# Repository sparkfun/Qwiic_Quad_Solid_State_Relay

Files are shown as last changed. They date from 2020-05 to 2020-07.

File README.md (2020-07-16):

SparkFun Qwiic Quad Solid State Relay Kit
========================================

SparkFun Qwiic Dual Solid State Relay

[*SparkFun Qwiic Dual Solid State Relay Kit (KIT-16833)*](https://www.sparkfun.com/products/16833)

The SparkFun Quad Solid State Relay Kit comes with four solid state relays you can assemble on to a single board allowing you to control all of them from a microcontroller via I<sup>2</sup>C with the Qwiic Ecosystem. The relays are rated for 40A @28-380VAC allowing you to harness some serious high voltage power from simple I<sup>2</sup>C commands from your favorite microcontroller.

The Qwiic Quad Solid State Relay comes requires some basic assembly to attach the relays and connect your AC load. It uses the simple [Qwiic interface](https://www.sparkfun.com/qwiic). No soldering, no voltage translation, no figuring out which pin is SDA or SCL, just plug and go!

**Note:** Controlling high voltage (110/220VAC) requires certain precautions. A beginner can do it but if you're wary of working with high voltage, you may want to consider the pre-made [IoT Power Relay](https://www.sparkfun.com/products/14236). It's not controlled via I<sup>2</sup>C but the IoT Power Relay contains shielding to prevent accidental shock.

Repository Contents
-------------------

* **/Documentation** - Data sheets, additional product information
* **/Firmware** - Latest firmware
* **/Hardware** - Eagle design files (.brd, .sch)
* **/Production** - Production panel files (.brd)

Documentation
--------------
* **[SparkFun Qwiic Relay Arduino Library](https://github.com/sparkfun/SparkFun_Qwiic_Relay_Arduino_Library)** - Arduino library for SparkFun Qwiic Relay boards.
* **[Hookup Guide](https://learn.sparkfun.com/tutorials/sparkfun-qwiic-quad-solid-state-relay-kit-hookup-guide)** - Basic hookup guide for the Qwiic Dual Solid State Relay.

Product Versions
----------------
* [KIT-16833](https://www.sparkfun.com/products/16810)- Initial release of the Qwiic Quad Solid State Relay Kit.

License Information
-------------------

This product is _**open source**_! 

Please review the LICENSE.md file for license information. 

If you have any questions or concerns on licensing, please contact technical support on our [SparkFun forums](https://forum.sparkfun.com/viewforum.php?f=152).

Distributed as-is; no warranty is given.

- Your friends at SparkFun.

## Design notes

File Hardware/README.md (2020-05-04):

SparkFun <PRODUCT NAME> Design Files
=====================================

The .sch and .brd files hare are Eagle CAD schematic and PCB design files from SparkFun Electronics.
A freeware version of Eagle can be found [here](http://www.cadsoftusa.com/download-eagle/freeware/).

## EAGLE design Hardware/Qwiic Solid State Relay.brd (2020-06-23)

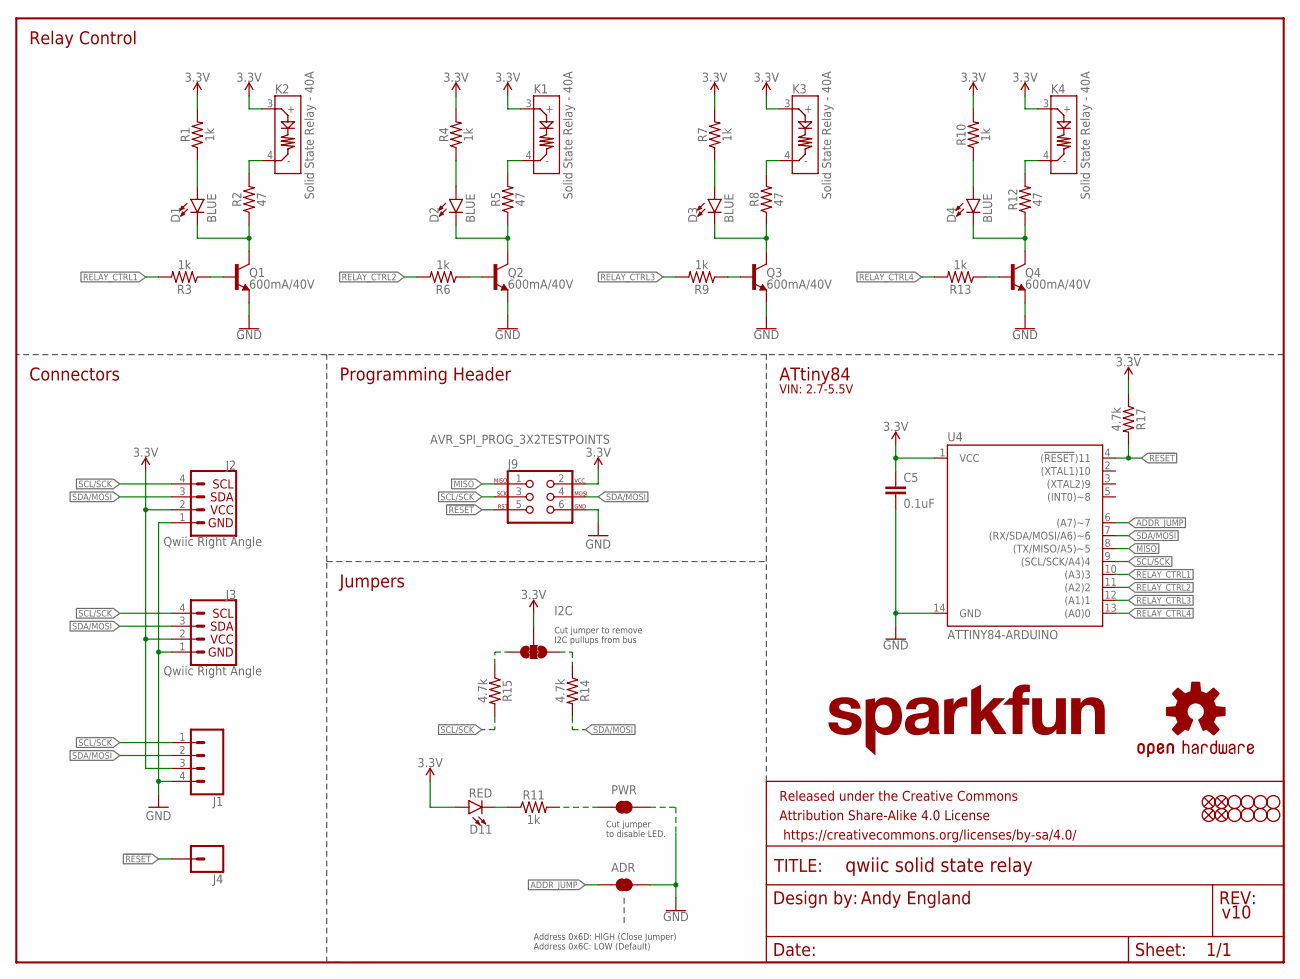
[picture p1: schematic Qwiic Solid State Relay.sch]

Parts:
ADR: JUMPER-SMT_2_NC_TRACE_SILK; SMT-JUMPER_2_NC_TRACE_SILK
C5: 0.1uF; 0603
D1, D2, D3, D4: BLUE; LED-0603
D11: RED; LED-0603
FD1, FD2, FD3, FD4: FIDUCIAL1X2; FIDUCIAL-1X2
FRAME1: FRAME-LETTER; CREATIVE_COMMONS
I2C: JUMPER-SMT_3_2-NC_TRACE_SILK; SMT-JUMPER_3_2-NC_TRACE_SILK
J1: CONN_041X04_NO_SILK; 1X04_NO_SILK
J2, J3: Qwiic Right Angle; JST04_1MM_RA
J4: CONN_01PTH_NO_SILK_YES_STOP; 1X01_NO_SILK
J9: AVR_SPI_PROG_3X2TESTPOINTS; 2X3_TEST_POINTS
JP1, JP2, JP3, JP4, JP5, JP6, JP7, JP8: STAND-OFF
K1, K2, K3, K4: Solid State Relay - 40A; SSR-40DA-H
LOGO1: SFE_LOGO_NAME1_INCH; SFE_LOGO_NAME_1
LOGO2: OSHW-LOGOS; OSHW-LOGO-S
PWR: JUMPER-SMT_2_NC_TRACE_SILK; SMT-JUMPER_2_NC_TRACE_SILK
Q1, Q2, Q3, Q4: 600mA/40V; SOT23-3
R1, R3, R4, R6, R7, R9, R10, R11, R13: 1k; 0603
R2, R5, R8, R12: 47; 0603
R14, R15, R17: 4.7k; 0603
U4: ATTINY84-ARDUINO; SO14

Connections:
3.3V: C5.1, D11.A, I2C.2, J1.3, J2.2, J3.2, J9.2, K1.3 (+), K2.3 (+), K3.3 (+), K4.3 (+), R1.2, R4.2, R7.2, R10.2, R17.1, U4.1 (VCC)
!RESET: J4.1, J9.5, R17.2, U4.4 ((!RESET!)11)
ADDR_JUMP: ADR.1, U4.6 ((A7)~7)
GND: ADR.2, C5.2, J1.4, J2.1, J3.1, J9.6, PWR.1, Q1.2 (E), Q2.2 (E), Q3.2 (E), Q4.2 (E), U4.14 (GND)
MISO: J9.1, U4.8 ((TX/MISO/A5)~5)
unnamed: D2.C, Q2.3 (C), R5.1
unnamed: D1.C, Q1.3 (C), R2.1
unnamed: K1.4 (-), R5.2
unnamed: D2.A, R4.1
unnamed: D3.C, Q3.3 (C), R8.1
unnamed: K3.4 (-), R8.2
unnamed: D1.A, R1.1
unnamed: D3.A, R7.1
unnamed: D4.C, Q4.3 (C), R12.1
unnamed: K2.4 (-), R2.2
unnamed: K4.4 (-), R12.2
unnamed: D4.A, R10.1
unnamed: D11.C, R11.1
unnamed: PWR.2, R11.2
unnamed: I2C.3, R15.1
unnamed: I2C.1, R14.1
OPTO_1: Q1.1 (B), R3.1
OPTO_2: Q2.1 (B), R6.1
OPTO_3: Q3.1 (B), R9.1
OPTO_4: Q4.1 (B), R13.1
RELAY_CTRL1: R3.2, U4.10 ((A3)3)
RELAY_CTRL2: R6.2, U4.11 ((A2)2)
RELAY_CTRL3: R9.2, U4.12 ((A1)1)
RELAY_CTRL4: R13.2, U4.13 ((A0)0)
SCL/SCK: J1.1, J2.4, J3.4, J9.3, R15.2, U4.9 ((SCL/SCK/A4)4)
SDA/MOSI: J1.2, J2.3, J3.3, J9.4, R14.2, U4.7 ((RX/SDA/MOSI/A6)~6)

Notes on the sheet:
Andy England
v10
Connectors
ATtiny84
Programming Header
Address 0x6D: HIGH (Close Jumper) Address 0x6C: LOW (Default)
Cut jumper to disable LED.
Jumpers
Relay Control
Cut jumper to remove I2C pullups from bus
VIN: 2.7-5.5V

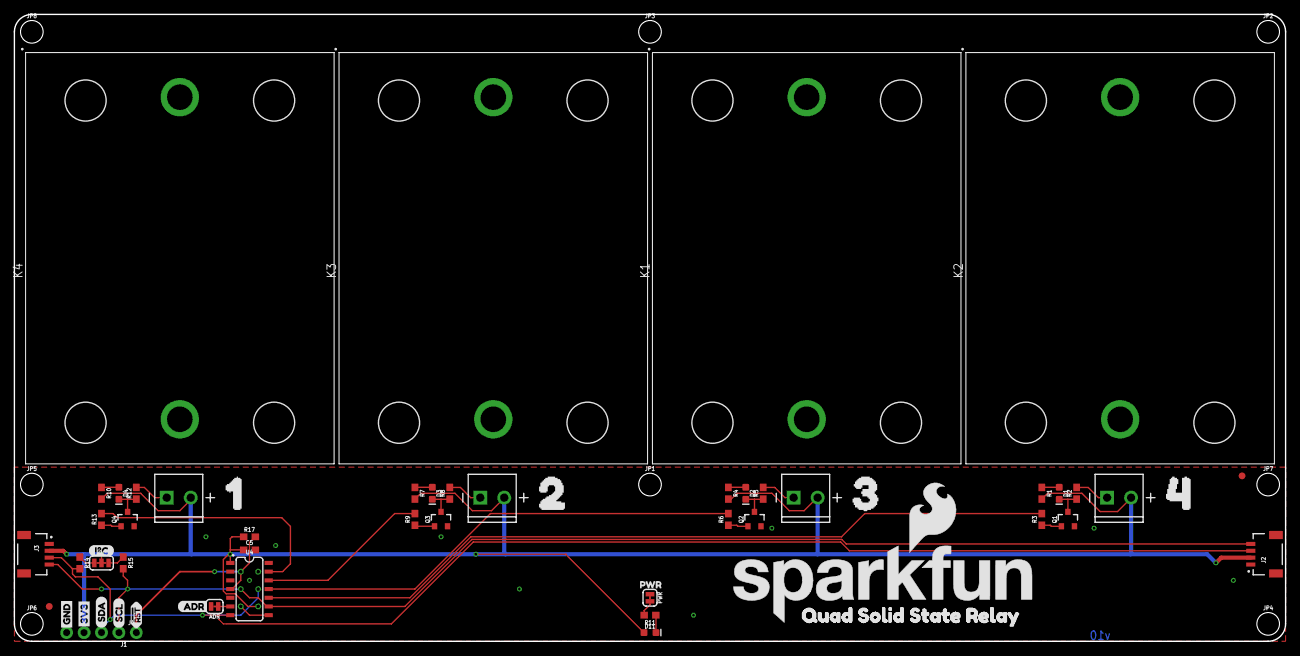
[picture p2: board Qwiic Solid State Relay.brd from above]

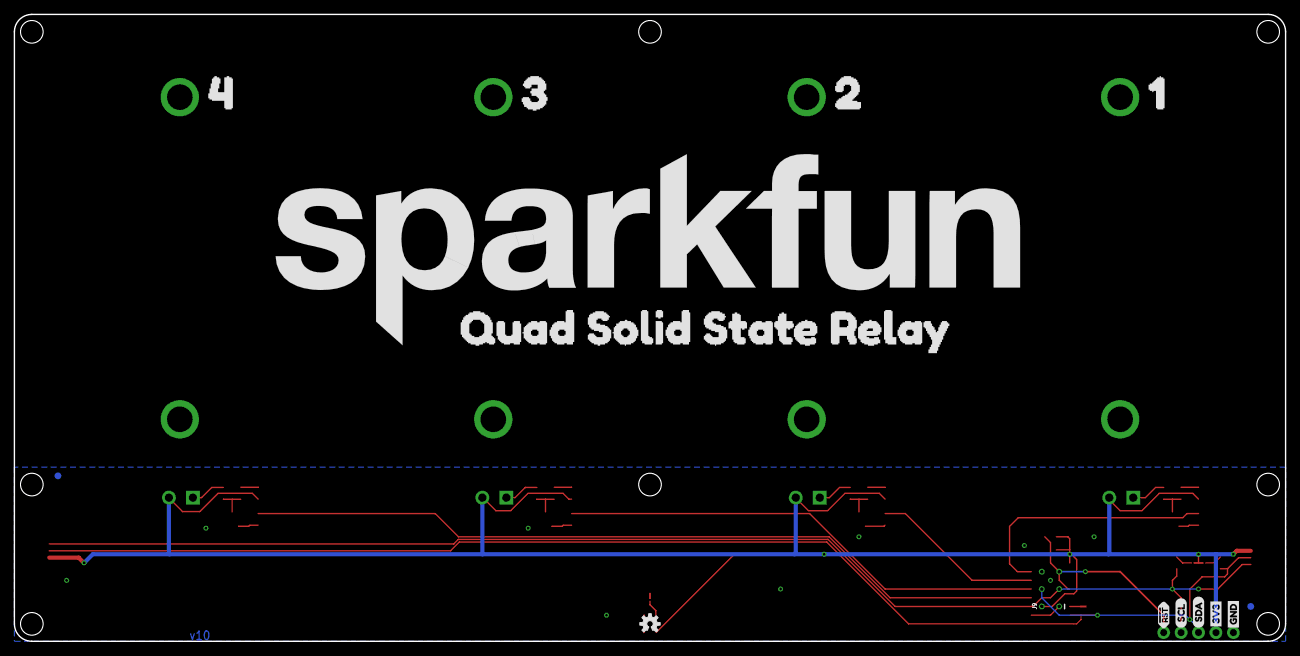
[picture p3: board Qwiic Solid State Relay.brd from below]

Board: 2 copper layers, 185.4 x 91.4 mm, 79 parts (15 on the bottom side), 31 nets.

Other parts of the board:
U$1: SFE_LOGO_NAME_FLAME_.4
U$2, U$3, U$4: QUAD_SOLID_STATE_RELAY0
U$5, U$9: 11
U$6, U$10: 22
U$7, U$11: 33
U$8, U$12: 44
U$13, U$14: GND_P
U$15: I2C
U$16, U$17: 3V3_P
U$18, U$19: SCL_IO
U$20, U$21: SDA_IO
U$22: PWR_TO
U$23: ADR3
U$24, U$25: !RST_I

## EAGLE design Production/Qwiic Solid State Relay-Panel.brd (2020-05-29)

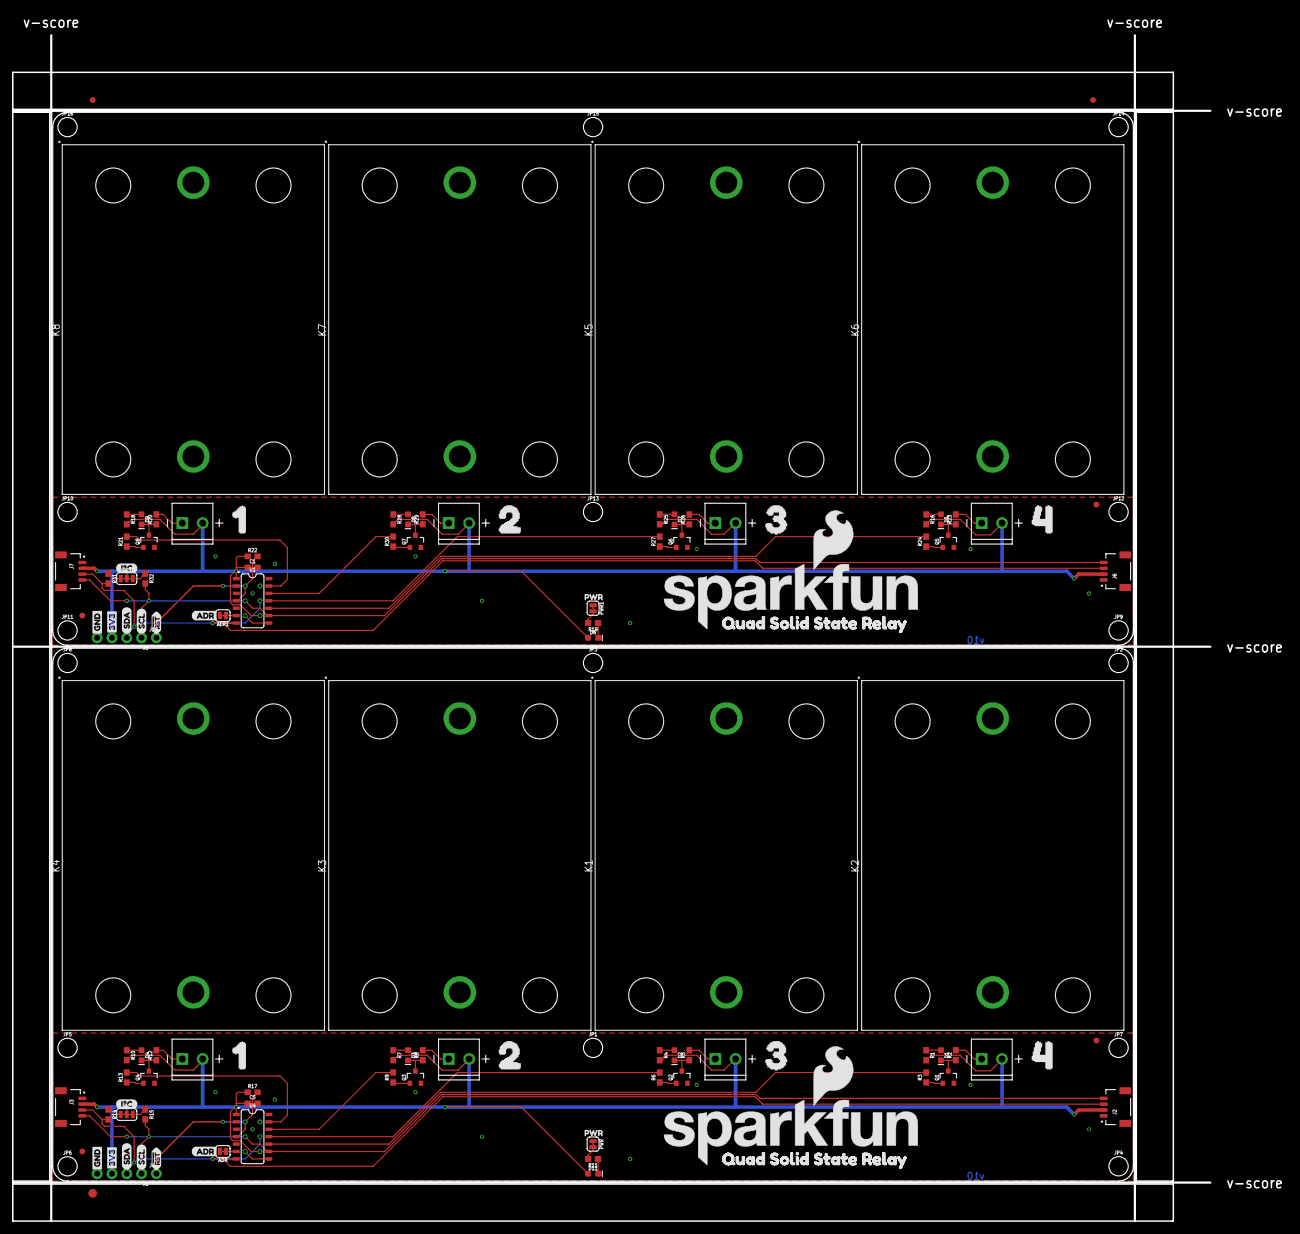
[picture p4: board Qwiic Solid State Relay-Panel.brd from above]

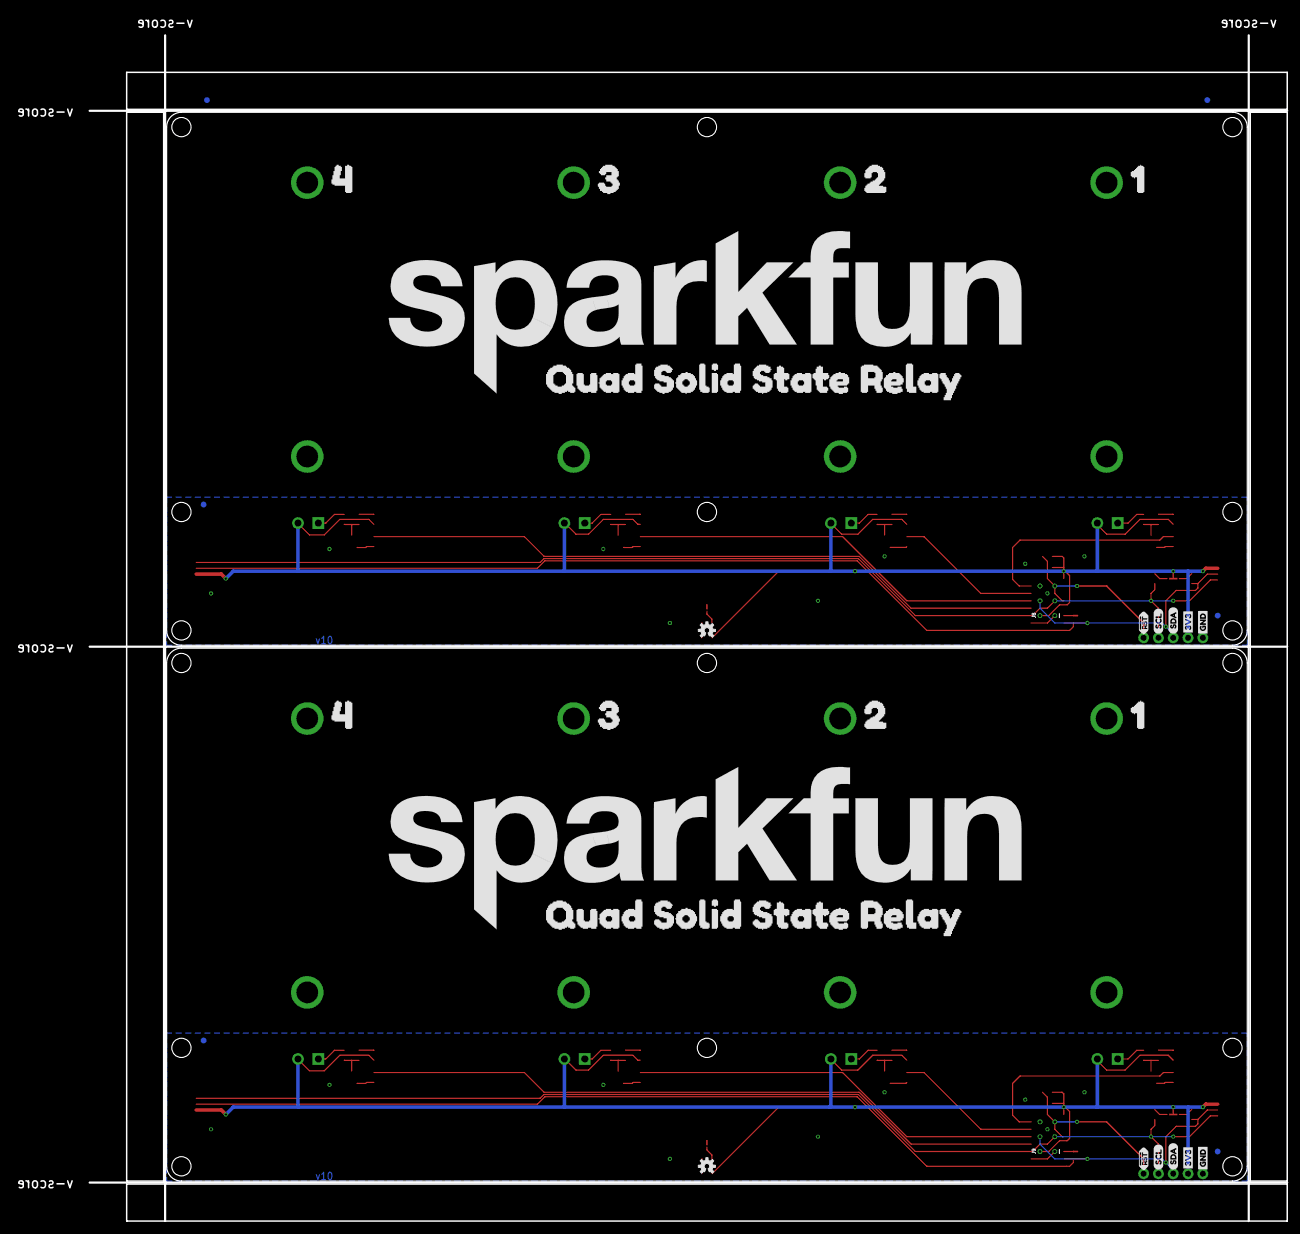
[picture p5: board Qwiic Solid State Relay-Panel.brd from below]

Board: 2 copper layers, 205.5 x 203.5 mm, 161 parts (32 on the bottom side), 62 nets.

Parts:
ADR, ADR1: JUMPER-SMT_2_NC_TRACE_SILK; SMT-JUMPER_2_NC_TRACE_SILK
C1, C5: 0.1uF; 0603
D1, D2, D3, D4, D5, D7, D8, D9: BLUE; LED-0603
D6, D11: RED; LED-0603
E$1, E$2, E$3, E$4: FIDUCIAL-1X2
E$5: FIDUCIAL-1.5X3
FD1, FD2, FD3, FD4, FD5, FD6, FD7, FD8: FIDUCIAL1X2; FIDUCIAL-1X2
I2C, I2C1: JUMPER-SMT_3_2-NC_TRACE_SILK; SMT-JUMPER_3_2-NC_TRACE_SILK
J1, J5: 1X04_NO_SILK
J2, J3, J6, J7: Qwiic Right Angle; JST04_1MM_RA
J4, J10: 1X01_NO_SILK
J8, J9: AVR_SPI_PROG_3X2TESTPOINTS; 2X3_TEST_POINTS
JP1, JP2, JP3, JP4, JP5, JP6, JP7, JP8, JP9, JP10, JP11, JP12, JP13, JP14, JP15, JP16: STAND-OFF
K1, K2, K3, K4, K5, K6, K7, K8: Solid State Relay - 40A; SSR-40DA-H
LOGO1, LOGO4: SFE_LOGO_NAME1_INCH; SFE_LOGO_NAME_1
LOGO2, LOGO3: OSHW-LOGOS; OSHW-LOGO-S
PWR, PWR1: JUMPER-SMT_2_NC_TRACE_SILK; SMT-JUMPER_2_NC_TRACE_SILK
Q1, Q2, Q3, Q4, Q5, Q6, Q7, Q8: 600mA/40V; SOT23-3
R1, R3, R4, R6, R7, R9, R10, R11, R13, R16, R18, R19, R21, R24, R25, R27, R28, R30: 1k; 0603
R2, R5, R8, R12, R20, R23, R26, R29: 47; 0603
R14, R15, R17, R22, R31, R32: 4.7k; 0603
U1, U4: ATTINY84-ARDUINO; SO14
U$1, U$26: SFE_LOGO_NAME_FLAME_.4
U$2, U$3, U$4, U$27, U$28, U$29: QUAD_SOLID_STATE_RELAY0
U$5, U$9, U$30, U$34: 11
U$6, U$10, U$31, U$35: 22
U$7, U$11, U$32, U$36: 33
U$8, U$12, U$33, U$37: 44
U$13, U$14, U$38, U$39: GND_P
U$15, U$40: I2C
U$16, U$17, U$41, U$42: 3V3_P
U$18, U$19, U$43, U$44: SCL_IO
U$20, U$21, U$45, U$46: SDA_IO
U$22, U$47: PWR_TO
U$23, U$48: ADR3
U$24, U$25, U$49, U$50: !RST_I

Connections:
3.3V: C5.1, D11.A, I2C.2, J1.3, J2.2, J3.2, J9.2, K1.2, K2.2, K3.2, K4.2, R1.2, R4.2, R7.2, R10.2, R17.1, U4.1
3.3V1: C1.1, D6.A, I2C1.2, J5.3, J6.2, J7.2, J8.2, K5.2, K6.2, K7.2, K8.2, R16.2, R18.2, R22.1, R25.2, R28.2, U1.1
!RESET: J4.1, J9.5, R17.2, U4.4
!RESET1: J8.5, J10.1, R22.2, U1.4
ADDR_JUMP: ADR.1, U4.6
ADDR_JUMP1: ADR1.1, U1.6
GND: ADR.2, C5.2, J1.4, J2.1, J3.1, J9.6, PWR.1, Q1.2, Q2.2, Q3.2, Q4.2, U4.14
GND1: ADR1.2, C1.2, J5.4, J6.1, J7.1, J8.6, PWR1.1, Q5.2, Q6.2, Q7.2, Q8.2, U1.14
MISO: J9.1, U4.8
MISO1: J8.1, U1.8
unnamed: D2.C, Q2.3, R5.1
unnamed: D1.C, Q1.3, R2.1
unnamed: K1.1, R5.2
unnamed: D2.A, R4.1
unnamed: D3.C, Q3.3, R8.1
unnamed: K3.1, R8.2
unnamed: D1.A, R1.1
unnamed: D3.A, R7.1
unnamed: D4.C, Q4.3, R12.1
unnamed: K2.1, R2.2
unnamed: K4.1, R12.2
unnamed: D4.A, R10.1
unnamed: D11.C, R11.1
unnamed: PWR.2, R11.2
unnamed: I2C.3, R15.1
unnamed: I2C.1, R14.1
unnamed: D6.C, R19.1
unnamed: PWR1.2, R19.2
unnamed: D5.C, Q5.3, R23.1
unnamed: K6.1, R23.2
unnamed: D5.A, R16.1
unnamed: D7.C, Q6.3, R26.1
unnamed: K5.1, R26.2
unnamed: D7.A, R25.1
unnamed: D8.C, Q7.3, R29.1
unnamed: K7.1, R29.2
unnamed: D8.A, R28.1
unnamed: D9.C, Q8.3, R20.1
unnamed: K8.1, R20.2
unnamed: D9.A, R18.1
unnamed: I2C1.3, R32.1
unnamed: I2C1.1, R31.1
OPTO_1: Q1.1, R3.1
OPTO_2: Q2.1, R6.1
OPTO_3: Q3.1, R9.1
OPTO_4: Q4.1, R13.1
OPTO_5: Q5.1, R24.1
OPTO_6: Q6.1, R27.1
OPTO_7: Q7.1, R30.1
OPTO_8: Q8.1, R21.1
RELAY_CTRL1: R3.2, U4.10
RELAY_CTRL2: R6.2, U4.11
RELAY_CTRL3: R9.2, U4.12
RELAY_CTRL4: R13.2, U4.13
RELAY_CTRL5: R24.2, U1.10
RELAY_CTRL6: R27.2, U1.11
RELAY_CTRL7: R30.2, U1.12
RELAY_CTRL8: R21.2, U1.13
SCL/SCK: J1.1, J2.4, J3.4, J9.3, R15.2, U4.9
SCL/SCK1: J5.1, J6.4, J7.4, J8.3, R32.2, U1.9
SDA/MOSI: J1.2, J2.3, J3.3, J9.4, R14.2, U4.7
SDA/MOSI1: J5.2, J6.3, J7.3, J8.4, R31.2, U1.7

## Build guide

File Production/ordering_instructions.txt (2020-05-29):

panel size, 200x191mm
PCB thickness, 1.6mm
number of layers, 2
soldermask color, Red
silkscreen color, White
oz copper, 1oz
finish, HASL lead free
stencils, top
pcs per panel, 2
min trace width, 0.1778mm / 0.0070in
min drill size, 0.3810mm / 0.0150in

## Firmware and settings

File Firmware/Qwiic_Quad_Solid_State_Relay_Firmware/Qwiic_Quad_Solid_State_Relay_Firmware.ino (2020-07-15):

/*
  An I2C based KeyPad
  By: Elias Santistevan
  SparkFun Electronics
  Date: October 2018
  License: This code is public domain but you buy me a beer if you use this and we meet someday (Beerware license).

  Feel like supporting our work? Buy a board from SparkFun!
	<Product Page Here>

  To install support for ATtiny84 in Arduino IDE: https://github.com/SpenceKonde/ATTinyCore/blob/master/Installation.md
  This core is installed from the Board Manager menu
  This core has built in support for I2C S/M and serial
  If you have Dave Mellis' ATtiny installed you may need to remove it from \Users\xx\AppData\Local\Arduino15\Packages

  To support 400kHz I2C communication reliably ATtiny84 needs to run at 8MHz. This requires user to
  click on 'Burn Bootloader' before code is loaded.
*/

#include <Wire.h>

#include <EEPROM.h>

#define LOCATION_I2C_ADDRESS 0x01 //Location in EEPROM where the I2C address is stored
#define I2C_ADDRESS_DEFAULT 8 //0x08 Default address
#define I2C_ADDRESS_JUMPER 9 //0x09 Address if address jumper is closed

#define COMMAND_CHANGE_ADDRESS 0xC7

#define NUM_RELAYS 4

#define RELAY_ONE 0
#define RELAY_TWO 1
#define RELAY_THREE 2
#define RELAY_FOUR 3

// Commands that toggle the relays.
#define RELAY_ONE_TOGGLE 0x01
#define RELAY_TWO_TOGGLE 0x02
#define RELAY_THREE_TOGGLE 0x03
#define RELAY_FOUR_TOGGLE 0x04
#define RELAY_ONE_PWM 0x10
#define RELAY_TWO_PWM 0x11
#define RELAY_THREE_PWM 0x12
#define RELAY_FOUR_PWM 0x13

#define SLOW_PWM_FREQUENCY 1
#define SLOW_PWM_MS SLOW_PWM_FREQUENCY * 1000 //Time for one full PWM cycle
#define SLOW_PWM_RESOLUTION 120.0
#define SLOW_PWM_STEP_TIME SLOW_PWM_MS / SLOW_PWM_RESOLUTION // Time per LSB in ms
#define TURN_ALL_OFF 0xA
#define TURN_ALL_ON 0xB
#define TOGGLE_ALL 0xC

// Commands to request the state of the relay, whether it is currently on or
// off.
#define RELAY_STATUS_ONE  0x05
#define RELAY_STATUS_TWO  0x06
#define RELAY_STATUS_THREE 0x07
#define RELAY_STATUS_FOUR 0x08

// Messages for requests that state whether a relay is on or off.
#define RELAY_IS_ON 0xF
#define RELAY_IS_OFF 0x0

volatile uint8_t setting_i2c_address = I2C_ADDRESS_DEFAULT;
volatile uint8_t COMMAND;  //Variable for incoming I2C commands.

const uint8_t addrPin = 7;
const uint8_t resetPin = 11;

// This 'status' array keeps track of the state of the relays.
uint8_t status[] = {RELAY_IS_OFF, RELAY_IS_OFF, RELAY_IS_OFF, RELAY_IS_OFF};
uint8_t pwmValues[] = {0, 0, 0, 0};
uint8_t relayPins[] = {RELAY_ONE, RELAY_TWO, RELAY_THREE, RELAY_FOUR};
uint32_t pwmOffTime[] = {0, 0, 0, 0};
uint32_t startTime = 0;
uint32_t now = 0;
uint32_t elapsed = 0;
bool beginPWM = true;

void setup(void)
{
  pinMode(addrPin, INPUT_PULLUP); //Default HIGH = 0x6D or 109
  pinMode(resetPin, INPUT_PULLUP);

  for (uint8_t relayNum = 0; relayNum < NUM_RELAYS; relayNum++) {
    pinMode(relayPins[relayNum], OUTPUT); //Set relay pins as output
  }

  readSystemSettings(); //Load all system settings from EEPROM
  startI2C(); //Determine the I2C address we should be using and begin listening on I2C bus
}

void loop(void) {

  for (uint8_t relayNum = 0; relayNum < NUM_RELAYS; relayNum++)
  {
    if ((pwmValues[relayNum] != 0) && (pwmOffTime[relayNum] == 0))
    {
      if (beginPWM == true)
      {
        startTime = millis();
        beginPWM = false;
      }
      digitalWrite(relayNum, HIGH);
      status[relayNum] = RELAY_IS_ON;
      pwmOffTime[relayNum] = startTime + (pwmValues[relayNum] * SLOW_PWM_STEP_TIME);
    }
  }
  now = millis();
  elapsed = now - startTime;
  for (uint8_t relayNum = 0; relayNum < NUM_RELAYS; relayNum++)
  {
    if ((SLOW_PWM_STEP_TIME * pwmValues[relayNum]) < elapsed && beginPWM == false)
    {
      digitalWrite(relayNum, LOW);

      status[relayNum] = RELAY_IS_OFF;
    }
  }
  now = millis();
  elapsed = now - startTime;
  if (elapsed >= SLOW_PWM_MS)
  {
    beginPWM = true;
    for (uint8_t relayNum = 0; relayNum < NUM_RELAYS; relayNum++)
    {
      pwmOffTime[relayNum] = 0;
    }
  }
}

void receiveEvent(int numberOfBytesReceived)
{
  while ( Wire.available() ) {
    //Record uint8_ts to local array
    COMMAND = Wire.read();

    if (COMMAND == COMMAND_CHANGE_ADDRESS) { //Set new I2C address
      if (Wire.available()) {
        setting_i2c_address = Wire.read();

        //Error check
        if (setting_i2c_address < 0x08 || setting_i2c_address > 0x77)
          continue; //Command failed. This address is out of bounds.

        EEPROM.write(LOCATION_I2C_ADDRESS, setting_i2c_address);

        //Our I2C address may have changed because of user's command
        startI2C(); //Determine the I2C address we should be using and begin listening on I2C bus
      }
    }

    // Relay control for relay 1, check the state, toggle the relay, change the
    // state.
    else if (COMMAND == RELAY_ONE_TOGGLE) {
      if (status[0] == RELAY_IS_OFF) {
        digitalWrite(RELAY_ONE, HIGH);
        status[0] = RELAY_IS_ON;
      }
      else if (status[0] == RELAY_IS_ON ) {
        digitalWrite(RELAY_ONE, LOW);
        status[0] = RELAY_IS_OFF;
      }
    }

    // Relay control for relay 2, check the state, toggle the relay, change the
    // state.
    else if (COMMAND == RELAY_TWO_TOGGLE) {
      if (status[1] == RELAY_IS_OFF) {
        digitalWrite(RELAY_TWO, HIGH);
        status[1] = RELAY_IS_ON;
      }
      else if (status[1] == RELAY_IS_ON ) {
        digitalWrite(RELAY_TWO, LOW);
        status[1] = RELAY_IS_OFF;
      }
    }

    // Relay control for relay 3, check the state, toggle the relay, change the
    // state.
    else if (COMMAND == RELAY_THREE_TOGGLE) {
      if (status[2] == RELAY_IS_OFF) {
        digitalWrite(RELAY_THREE, HIGH);
        status[2] = RELAY_IS_ON;
      }
      else if (status[2] == RELAY_IS_ON ) {
        digitalWrite(RELAY_THREE, LOW);
        status[2] = RELAY_IS_OFF;
      }
    }

    // Relay control for relay 4, check the state, toggle the relay, change the
    // state.
    else if (COMMAND == RELAY_FOUR_TOGGLE) {
      if (status[3] == RELAY_IS_OFF) {
        digitalWrite(RELAY_FOUR, HIGH);
        status[3] = RELAY_IS_ON;
      }
      else if (status[3] == RELAY_IS_ON ) {
        digitalWrite(RELAY_FOUR, LOW);
        status[3] = RELAY_IS_OFF;
      }
    }

    else if (COMMAND == RELAY_ONE_PWM) {
      if (Wire.available())
      {
        pwmValues[0] = Wire.read();
      }
    }

    else if (COMMAND == RELAY_TWO_PWM) {
      if (Wire.available())
      {
        pwmValues[1] = Wire.read();
      }
    }

    else if (COMMAND == RELAY_THREE_PWM) {
      if (Wire.available())
      {
        pwmValues[2] = Wire.read();
      }
    }

    else if (COMMAND == RELAY_FOUR_PWM) {
      if (Wire.available())
      {
        pwmValues[3] = Wire.read();
      }
    }

    // Turn all relays off, record all of their states.
    else if (COMMAND == TURN_ALL_OFF) {
      digitalWrite(RELAY_ONE, LOW);
      digitalWrite(RELAY_TWO, LOW);
      digitalWrite(RELAY_THREE, LOW);
      digitalWrite(RELAY_FOUR, LOW);
      for (int i = 0; i < sizeof(status); i++) {
        status[i] = RELAY_IS_OFF;
      }
    }

    // Turn it up to ELEVEN, all on! Record their states to the status array.
    else if (COMMAND == TURN_ALL_ON) {
      digitalWrite(RELAY_ONE, HIGH);
      digitalWrite(RELAY_TWO, HIGH);
      digitalWrite(RELAY_THREE, HIGH);
      digitalWrite(RELAY_FOUR, HIGH);
      for (int i = 0; i < sizeof(status); i++) {
        status[i] = RELAY_IS_ON;
      }
    }

    // This command will put each relay into it's opposite state: relays that
    // are on will be turned off and vice versa.
    else if (COMMAND == TOGGLE_ALL) {
      for (int i = 0; i < sizeof(status); i++) {
        if (status[i] == RELAY_IS_ON) {
          // Remember that the relays are on pins 0-4, which aligns with the
          // status array. With that, I'll be using the iterator 'i' to write
          // the pins HIGH and LOW.
          digitalWrite(i, LOW);
          status[i] = RELAY_IS_OFF;
          continue;
        }
        //Would be an else statement, but for clarity....
        else if (status[i] == RELAY_IS_OFF) {
          digitalWrite(i, HIGH);
          status[i] = RELAY_IS_ON;
        }
      }
    }

  }
}

void requestEvent()
{
  // In the you want to request multiple relay states without having to do
  // multiple "requestFrom"'s in code, the request COMMAND will iterate through
  // the sequential response commands (0x05 -> 0x08). For example, if you
  // request 2 bytes, starting with relay three (0x07), then you'll receive the
  // state of relay three and relay four(0x08). If you request the state of
  // three relays, starting with four, you'll get four(0x08), one(0x05),
  // two(0x06) etc.

  if (COMMAND == RELAY_STATUS_ONE) {
    Wire.write(status[0]);
    COMMAND++;
  }
  if (COMMAND == RELAY_STATUS_TWO) {
    Wire.write(status[1]);
    COMMAND++;
  }
  if (COMMAND == RELAY_STATUS_THREE) {
    Wire.write(status[2]);
    COMMAND++;
  }
  if (COMMAND == RELAY_STATUS_FOUR) {
    Wire.write(status[3]);
    COMMAND++;
  }
  if (COMMAND == RELAY_ONE_PWM) {
    Wire.write(pwmValues[0]);
    COMMAND++;
  }
  if (COMMAND == RELAY_TWO_PWM) {
    Wire.write(pwmValues[1]);
    COMMAND++;
  }
  if (COMMAND == RELAY_THREE_PWM) {
    Wire.write(pwmValues[2]);
    COMMAND++;
  }
  if (COMMAND == RELAY_FOUR_PWM) {
    Wire.write(pwmValues[3]);
    COMMAND = 0x05;
  }
}

void readSystemSettings(void)
{
  //Read what I2C address we should use
  setting_i2c_address = EEPROM.read(LOCATION_I2C_ADDRESS);
  if (setting_i2c_address == 255) {
    setting_i2c_address = I2C_ADDRESS_DEFAULT; //By default, we listen for I2C_ADDRESS_DEFAULT
    EEPROM.write(LOCATION_I2C_ADDRESS, setting_i2c_address);
  }
}

//Begin listening on I2C bus as I2C slave using the global variable setting_i2c_address
void startI2C()
{
  Wire.end(); //Before we can change addresses we need to stop

  if (digitalRead(addrPin) == LOW) //Default HIGH
    Wire.begin(setting_i2c_address); //Start I2C and answer calls using address from EEPROM
  else
    Wire.begin(I2C_ADDRESS_JUMPER);//Closed jumper is LOW

  //The connections to the interrupts are severed when a Wire.begin occurs. So re-declare them.
  Wire.onReceive(receiveEvent);
  Wire.onRequest(requestEvent);
}

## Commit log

2020-05-20 adding silk
    [Qwiic Solid State Relay.GBL, Qwiic Solid State Relay.GBO, Qwiic Solid State Relay.GBP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]
2020-05-22 fixing overlap error, wire stub
    [Qwiic Solid State Relay.brd]
2020-05-26 updating for reds after design review, checklist
    [Board_Design_Checklist_Qwiic_SSR_v10.xls, Qwiic Solid State Relay.brd, Qwiic Solid State Relay.sch]
2020-05-26 forgot to save brd file for previous commit
    [Qwiic Solid State Relay.brd]
2020-05-29 adding panel
    [Board_Design_Checklist_Qwiic_SSR_v10.xls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]
2020-06-23 switching pin labels around to match SSR
    [Qwiic Solid State Relay.brd, Qwiic Solid State Relay.sch]
2020-07-14 finalizing changes to SlowPWM, 120Hz
2020-07-14 updating schematic address note
    [Qwiic Solid State Relay.sch]
2020-07-15 fixing SlowPWM relay start condition that would cause things to turn off
    [Qwiic_Quad_Solid_State_Relay_Firmware.ino]

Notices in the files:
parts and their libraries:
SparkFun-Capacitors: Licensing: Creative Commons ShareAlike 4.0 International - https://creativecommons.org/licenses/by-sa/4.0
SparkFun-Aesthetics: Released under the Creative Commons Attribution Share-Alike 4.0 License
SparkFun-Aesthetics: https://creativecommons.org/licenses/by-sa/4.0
